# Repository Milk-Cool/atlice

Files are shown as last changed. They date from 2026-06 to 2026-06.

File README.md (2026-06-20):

# atlice
attiny85-based multi-purpose lice hairclips

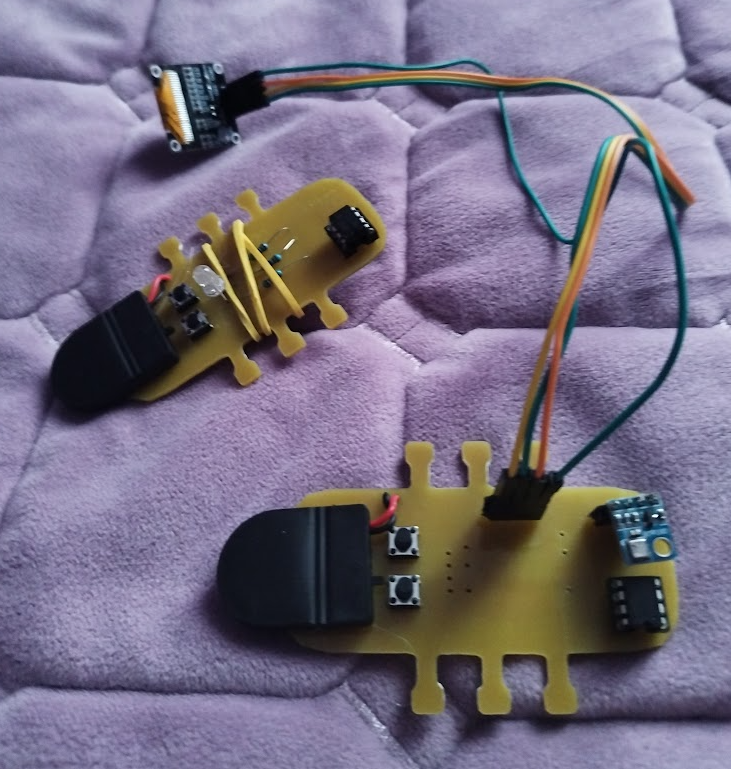
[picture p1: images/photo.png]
photo of the atlice

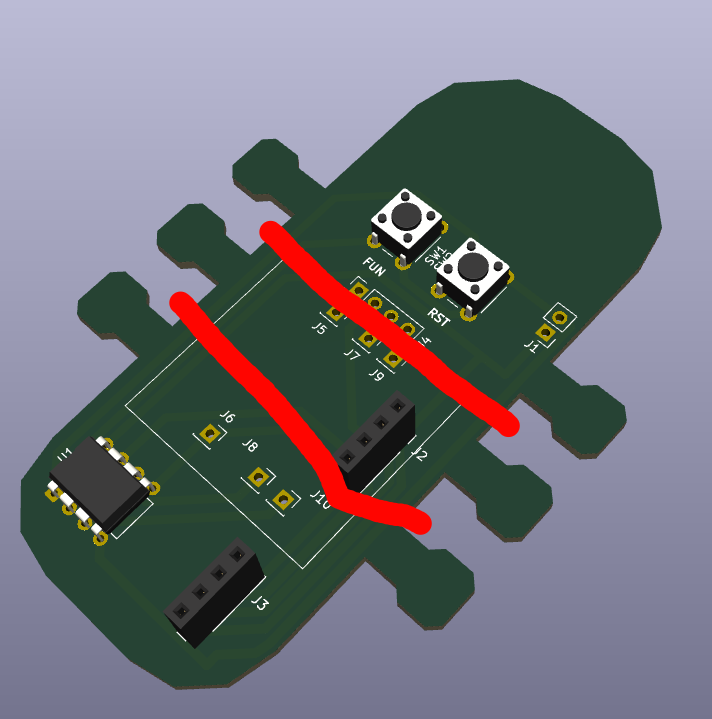
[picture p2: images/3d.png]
3d model


<small>[head image source](https://en.wiktionary.org/wiki/head)</small>

## what is this?
this is a hairclip that can be used as either a mood indicator, a tamagotchi, or a portable weather station. well, not a hairclip by itself -- a pcb that can be attached onto a hairclip with rubber bands. it has multiple firmware modes available, all of which let you use the device in their own unique ways. it is based on the attiny85 chip, which isn't too powerful but is more than enough for this.

## how do i use this?
first of all, get all the required components (listed in `bom.xml`, disregard components you don't need) and build it! the gerber files and the source project files are in this repo, too (see `kicad/`). here are some notes:
- get an SSD1306 display that a. works via i2c and b. has the power pin on the left. from what i could find, these also take 3V as the input just fine, which is perfect for our purposes since we use a CR2302 battery. (note: some sellers might send you the wrong type of display, like mine! please be aware of that)
- solder a 150Ohm resistor at J5-J6 and a 100Ohm resistor at J7-J8 and J9-J10.
- solder/attach the SSD1306 display facing inwards at J2, and the BMP180 temperature sensor also facing inwards at J3. the attiny85 goes at U1.
- attach the battery case at J1, with the top pin being the ground pin and the bottom pin being the +3V0 pin.

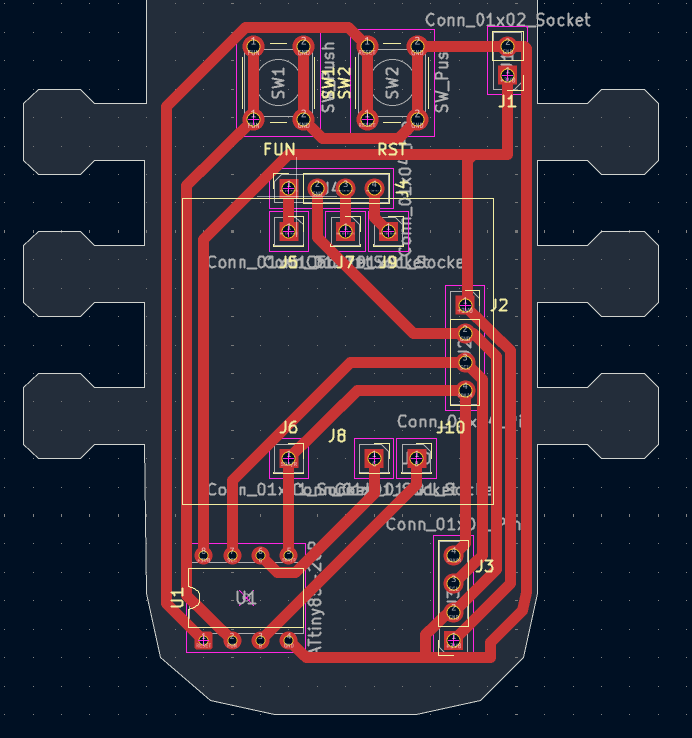
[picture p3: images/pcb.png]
pcb

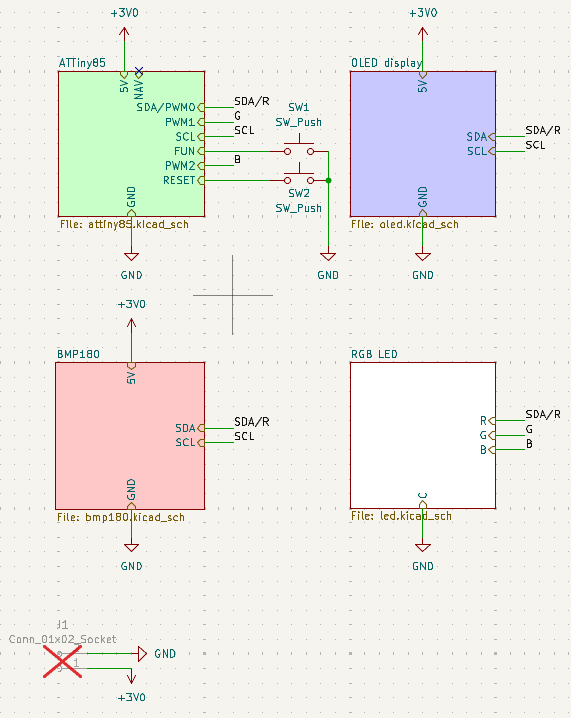
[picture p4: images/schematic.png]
schematic


you can then attach it to a hairclip using small rubber bands with the grooves on the pcb (the "legs" of the louse).

once you have built it, flash the attiny85 with the appropriate firmware from `firmware/`. (note: if you want to permanently solder the attiny85 to the board, flash it before that! it'll be very hard to do it otherwise.)
then just turn on the battery and enjoy!!

### controls
|mode|FUN|RST|
|-|-|-|
|mood indicator|-|change color/mood|
|weather station|-|turn on|
|tamagotchi|play with|feed/turn on|

## why was this made?
i have an old mood indicator hairclip (inspired by a pi pico hot glued to a hairclip, which was gifted to me by a friend), which also has an attiny85. i built it around december of 2025, and wanted to push the concept of wearable hairclips even further ever since then. this is my next attempt, hopefully it's actually good!!

## credits
- zine background: https://www.dreamstime.com/illustration/bug-wallpaper.html

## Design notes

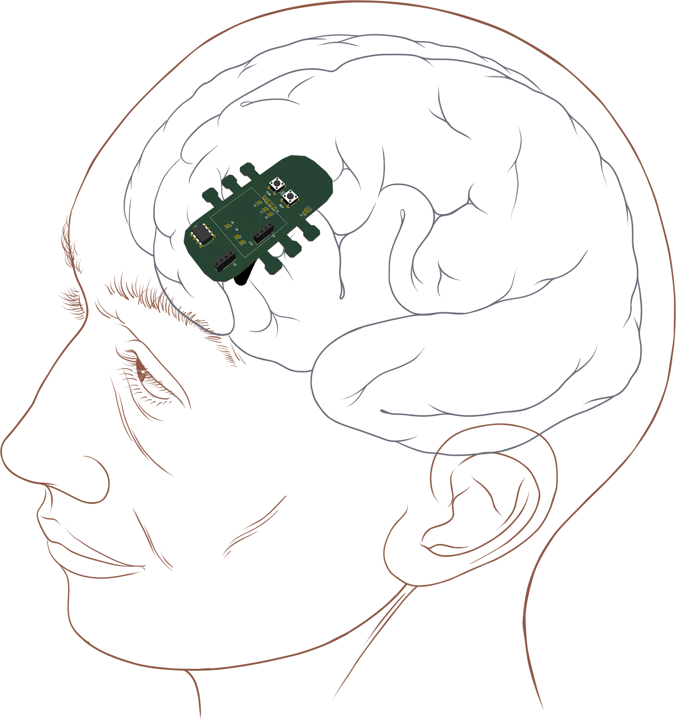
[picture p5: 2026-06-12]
images/drawing.png

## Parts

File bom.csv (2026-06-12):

Product name | Product link | Product cost | Product amount | Notes
100 Ohm resistor | https://www.aliexpress.us/item/3256811699109203.html | $0.01 | 2 | Link leads to listing with 100 pieces available only. Price specified per unit; it is $0.99 to buy 100 pcs.
150 Ohm resistor | https://www.aliexpress.us/item/3256811699109203.html | $0.01 | 1 | Link leads to listing with 100 pieces available only. Price specified per unit; it is $0.99 to buy 100 pcs.
4-pin female headers | https://www.aliexpress.us/item/2255801012106911.html | $0.14 | 4 | Two of these are for the attiny85; not required if you're planning to solder it permanently.
SSD1306 i2c OLED display | https://www.aliexpress.us/item/3256811467366210.html | $4.20 | 1 | Link leads to listing with 3 pieces available only. Price specified per unit; it is $12.60 to buy 3 pcs.
FG TC-6601-5.0-260-8.3 | https://www.lcsc.com/product-detail/C7528752.html | $0.03 | 2
CR2032 battery holder with switch | https://www.aliexpress.us/item/3256806989197470.html | $1.29 | 1
BMP180 | https://www.aliexpress.us/item/3256806939325524.html | $2.71 | 1
RGB LED | https://www.aliexpress.us/item/3256804777276319.html | $0.06 | 1 | Link leads to listing with 3 pieces available only. Price specified per unit; it is $12.60 to buy 3 pcs. Also choose the transparent cathode option.
Total |  | $8.45

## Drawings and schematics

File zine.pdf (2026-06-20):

## atlice - your (at)tiny lice buddies

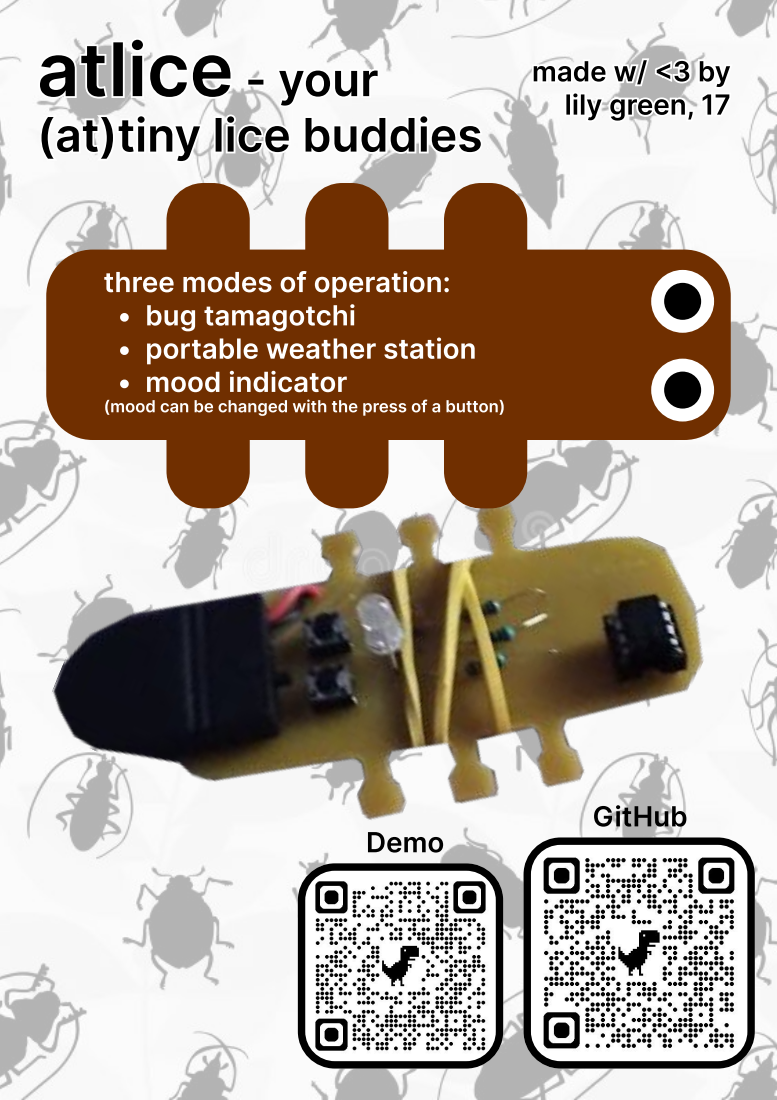
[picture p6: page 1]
made w/ <3 by lily green, 17; Demo; GitHub

three modes of operation:
bug tamagotchi
portable weather station
mood indicator
(mood can be changed with the press of a button)

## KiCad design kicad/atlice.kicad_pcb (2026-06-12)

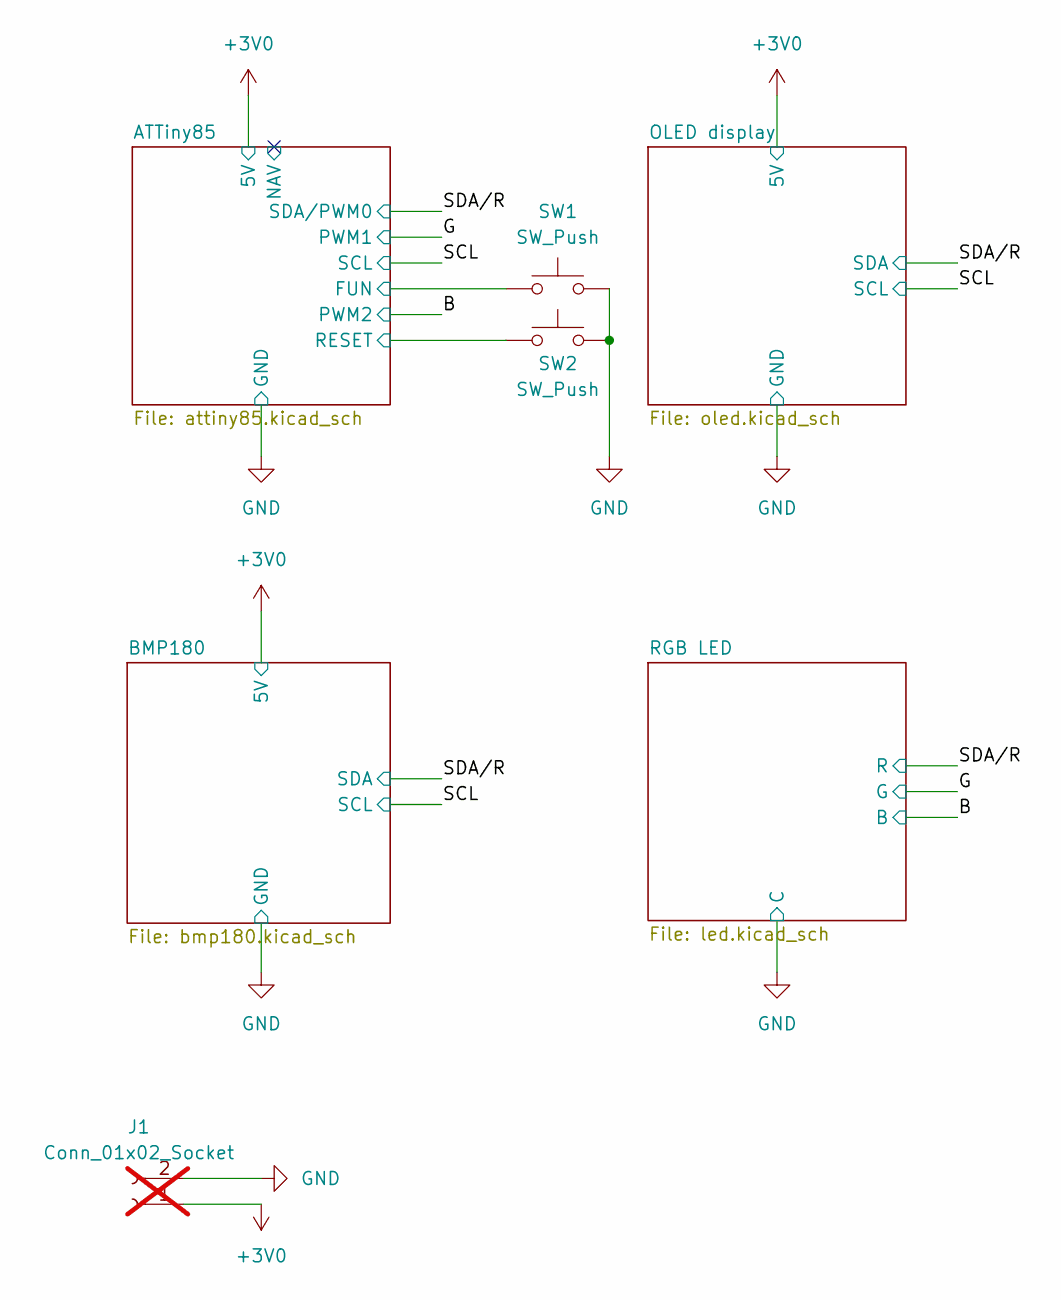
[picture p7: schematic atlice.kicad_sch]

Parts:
J1: Conn_01x02_Socket; PinHeader_1x02_P2.54mm_Vertical; not fitted
SW1, SW2: SW_Push; SW_PUSH_6mm

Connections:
+3V0: J1.1; also elsewhere on the board
/ATTiny85/FUN: SW1.1; also elsewhere on the board
/ATTiny85/RESET: SW2.1; also elsewhere on the board
GND: J1.2, SW1.2, SW2.2; also elsewhere on the board

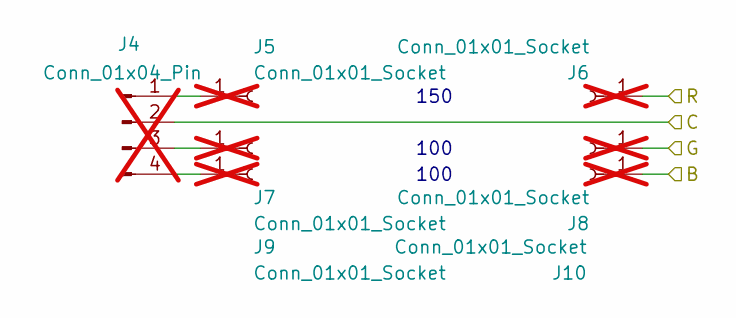
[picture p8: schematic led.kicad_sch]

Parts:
J4: Conn_01x04_Pin; PinSocket_1x04_P2.54mm_Vertical; not fitted
J5, J6, J7, J8, J9, J10: Conn_01x01_Socket; PinSocket_1x01_P2.54mm_Vertical; not fitted

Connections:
/B: J10.1 (Pin_1_1); also elsewhere on the board
/G: J8.1 (Pin_1_1); also elsewhere on the board
/SDA/R: J6.1 (Pin_1_1); also elsewhere on the board
GND: J4.2; also elsewhere on the board
unnamed: J4.1, J5.1 (Pin_1_1)
unnamed: J4.3, J7.1 (Pin_1_1)
unnamed: J4.4, J9.1 (Pin_1_1)

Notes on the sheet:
100
150

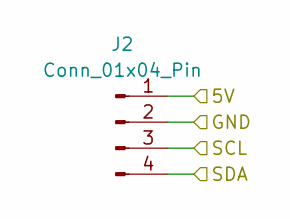
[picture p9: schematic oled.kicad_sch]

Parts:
J2: Conn_01x04_Pin; PinSocket_1x04_P2.54mm_Vertical

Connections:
+3V0: J2.1; also elsewhere on the board
/SCL: J2.3; also elsewhere on the board
/SDA/R: J2.4; also elsewhere on the board
GND: J2.2; also elsewhere on the board

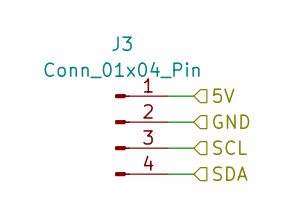
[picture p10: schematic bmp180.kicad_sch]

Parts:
J3: Conn_01x04_Pin; PinSocket_1x04_P2.54mm_Vertical

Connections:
+3V0: J3.1; also elsewhere on the board
/SCL: J3.3; also elsewhere on the board
/SDA/R: J3.4; also elsewhere on the board
GND: J3.2; also elsewhere on the board

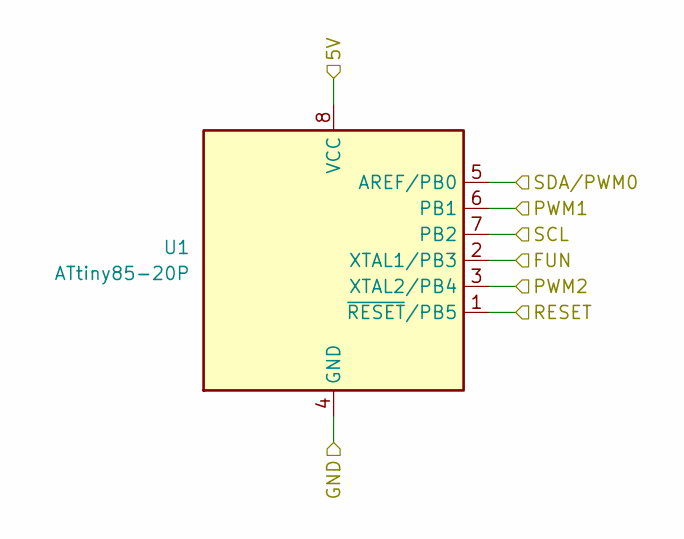
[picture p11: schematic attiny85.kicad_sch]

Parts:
U1: ATtiny85-20P; DIP-8_W7.62mm

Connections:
+3V0: U1.8 (VCC); also elsewhere on the board
/ATTiny85/FUN: U1.2 (XTAL1/PB3); also elsewhere on the board
/ATTiny85/RESET: U1.1 (~RESET/PB5); also elsewhere on the board
/B: U1.3 (XTAL2/PB4); also elsewhere on the board
/G: U1.6 (PB1); also elsewhere on the board
/SCL: U1.7 (PB2); also elsewhere on the board
/SDA/R: U1.5 (AREF/PB0); also elsewhere on the board
GND: U1.4 (GND); also elsewhere on the board

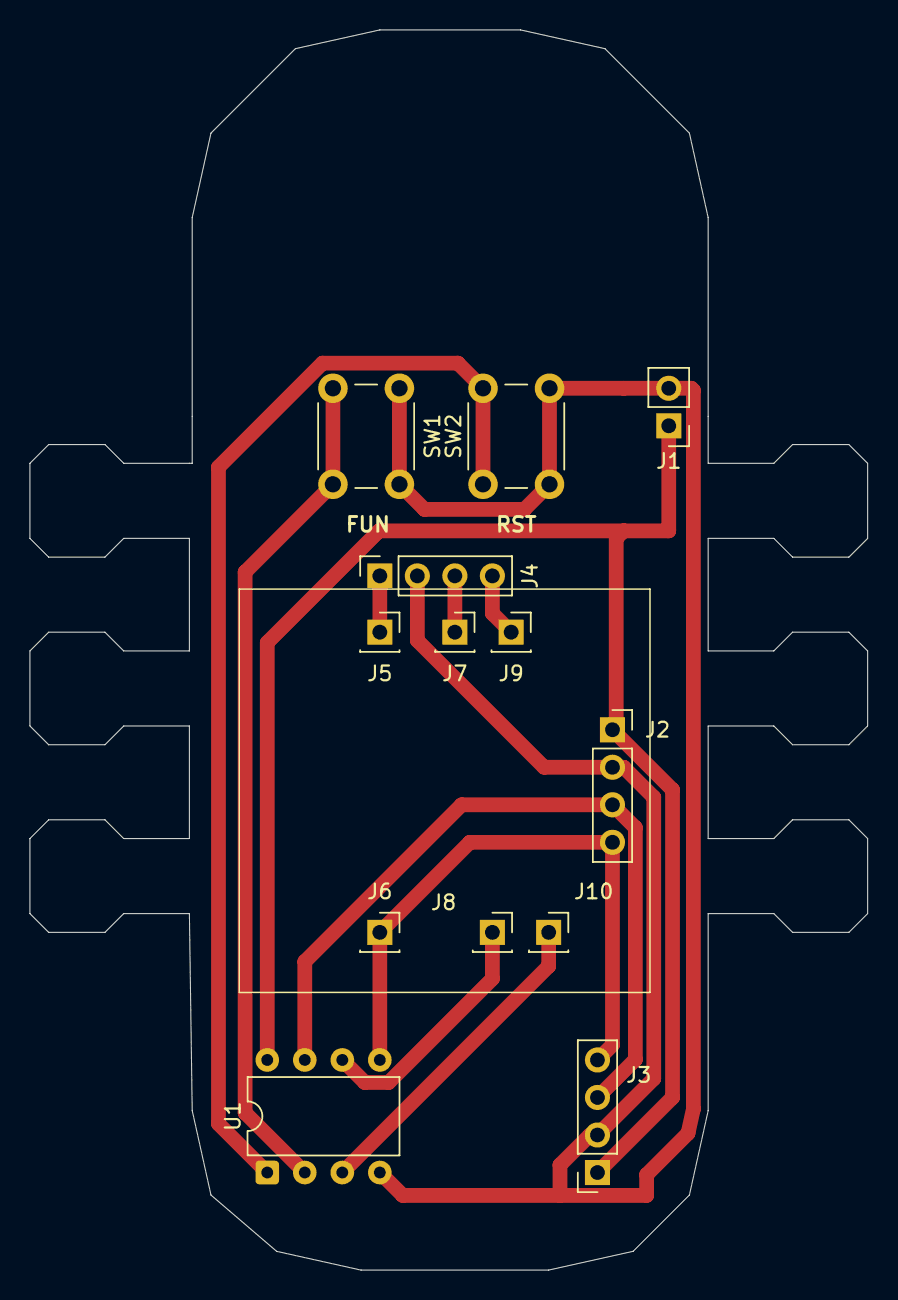
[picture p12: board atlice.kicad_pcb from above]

Board: 2 copper layers, 56.7 x 83.9 mm, 13 parts (0 on the bottom side), 11 nets.

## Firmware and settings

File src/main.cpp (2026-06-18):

#include <Arduino.h>
#include <avr/sleep.h>
#include <avr/wdt.h>
#include <EEPROM.h>

#define PIN_FUN 3

ISR(WDT_vect) {}

#if MOOD_INDICATOR
typedef struct {
    uint8_t r;
    uint8_t g;
    uint8_t b;
} Color;
Color colors[] = {
    { HIGH, LOW, LOW },
    { LOW, HIGH, LOW },
    { LOW, LOW, HIGH },
    { HIGH, HIGH, LOW },
    { LOW, HIGH, HIGH },
    { HIGH, LOW, HIGH },
    { HIGH, HIGH, HIGH },
    { HIGH, HIGH, HIGH }, // flashlight mode
};

uint8_t color;
#define COLOR_LEN (sizeof(colors) / sizeof(colors[0]))
#define LAST_COLOR (COLOR_LEN - 1) // flashlight mode

#define PIN_R 0
#define PIN_G 1
#define PIN_B 4
#elif TAMAGOTCHI
uint8_t hunger;
uint8_t fun;
uint8_t xp;
uint8_t lvl;

uint8_t counter;

static void load_tmg() {
    hunger = EEPROM.read(0);
    fun = EEPROM.read(1);
    xp = EEPROM.read(2);
    lvl = EEPROM.read(3);
}
static void save_tmg() {
    EEPROM.write(0, hunger);
    EEPROM.write(1, fun);
    EEPROM.write(2, xp);
    EEPROM.write(3, lvl);
}
#elif WEATHER_STATION
#include <TinyBMP280.h>
tbmp::TinyBMP180 bmp;
#endif

#if (TAMAGOTCHI || WEATHER_STATION)
#define SSD1306 0x3c
#include <Tiny4kOLED.h>
#endif

void sleep(bool is_long, bool wait = true, uint8_t long_to = WDTO_2S) {
    cli();
    wdt_reset();
    MCUSR &= ~(1 << WDRF);
    // WDTCR |= (1 << WDCE) | (1 << WDE);
    if(wait) {
        WDTCR = (1 << WDCE) | (1 << WDE);
        WDTCR = (1 << WDIE) | (is_long ? long_to : WDTO_120MS);
    }
    sei();

    set_sleep_mode(SLEEP_MODE_PWR_DOWN);
    sleep_enable();

    sleep_cpu();
    sleep_disable();

    wdt_disable();
}

void setup() {
#if TAMAGOTCHI
    wdt_disable();
#endif
    pinMode(PIN_FUN, INPUT_PULLUP);
    if(!digitalRead(PIN_FUN)) while(true) delay(100);

#if (TAMAGOTCHI || WEATHER_STATION)
    oled.begin(128, 64, sizeof(tiny4koled_init_128x64br), tiny4koled_init_128x64br);
    oled.clear();
    oled.on();
    oled.setFont(FONT8X16);
#endif

#if MOOD_INDICATOR
    pinMode(PIN_R, OUTPUT);
    pinMode(PIN_G, OUTPUT);
    pinMode(PIN_B, OUTPUT);

    color = EEPROM.read(0);
    if(color >= COLOR_LEN) color = 0;
    EEPROM.write(0, color + 1);
#endif

#if TAMAGOTCHI
    load_tmg();
    if(hunger > 120) {
        hunger = 0;
        fun = 0;
        xp = 0;
        lvl = 0;
    }
    if(hunger != 0) hunger--;
    save_tmg();

    oled.println(" \\O/");
    oled.println( " -O- ");
    oled.println( " /o\\");
    oled.setFont(FONT6X8);
    oled.print("HUN=");
    oled.print(hunger);
    oled.print(" FUN=");
    oled.println(fun);
    oled.print("XP=");
    oled.print(xp);
    oled.print(" LVL=");
    oled.print(lvl);

    for(uint16_t i = 0; i < 1000; i++) {
        delay(10);
        if(!digitalRead(PIN_FUN)) {
            if(fun != 20) fun++;
            xp++;
            if(xp == 20) {
                xp = 0;
                lvl++;
            }
            if(hunger != 20) hunger++;
            save_tmg();
            while(!digitalRead(PIN_FUN));
            wdt_enable(WDTO_15MS); // will this work? no idea tbh
            while(true);
        }
    }
    oled.clear();
    oled.off();
#elif WEATHER_STATION
    bmp.begin();
    float t = bmp.readTemperature();
    oled.print(t);
    oled.println(" C");
#endif
}
void loop() {
#if TAMAGOTCHI
    sleep(true, true, WDTO_8S);
    if(counter == 255) {
        if(fun != 0) fun--;
        if(hunger != 20) hunger++;
        save_tmg();
        counter = 0;
    }
    counter++;
#elif WEATHER_STATION
    delay(10000);
    oled.clear();
    oled.off();
    sleep(false, false);
#endif

#if MOOD_INDICATOR
    digitalWrite(PIN_R, colors[color].r);
    digitalWrite(PIN_G, colors[color].g);
    digitalWrite(PIN_B, colors[color].b);

    if(color == LAST_COLOR) sleep(false, false);

    sleep(false);

    digitalWrite(PIN_R, 0);
    digitalWrite(PIN_G, 0);
    digitalWrite(PIN_B, 0);

    sleep(true);
#endif
}
